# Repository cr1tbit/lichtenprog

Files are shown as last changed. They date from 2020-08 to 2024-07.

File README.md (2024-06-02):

## Lichtenprog - an rather-cheap-USB-to-UART-bridge-with-3v3-out

### Raison d'etre

The device is based on CP2102n - meaning it should work properly on any OS without messy drivers from unknown sources. It's also cheaper than legit FT232 chips.

Why can't I power my stuff from basic USB-to-UART bridges? Some of those serial adapters out there have basic 3.3V-out bulitin, coming usually from main IC's LDO output. Being able to supply like 100 miliamps. I want my full 500mA from the USB! Seriously, throwing that external LDO costs like 10 cents.

I also added an simple circut for estimating the connected device's current draw. You may left it unpopulated, to save like another 70c.

Honestly, I've found myself using this board to supply my 3v3 devices from wallplugs, it's just convenient to have like 10 of those.

## Customizing your Lichtenprog

After soldering your device, you may want to reprogram the CP2102n a little bit, in order to set:
 * TX/RX leds functionality (by default disabled)
 * Max current draw USB descriptor
 * Your custom name and manufacturer name (yay!)

Please, just do not modify PID and VID, or els you risk effectively bricking your brand new 3$ device.

To modify these values, you may use official "xpressconfigurator" from SiLabs

I couldn't make this tool to work on linux though - take a look at this CLI-based project, which should allow setting up basic stuff.

https://github.com/cr1tbit/cp210x-cfg

## Photo (outdated)

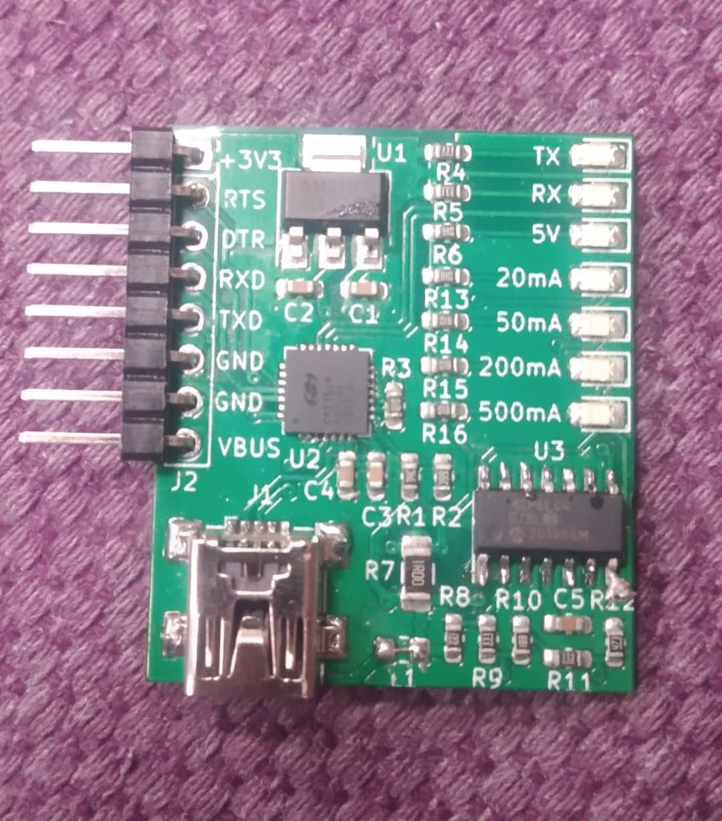
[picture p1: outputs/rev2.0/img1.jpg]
lichtenprog rev 2.0 photo


## License
The hardware design files, including schematics and PCB layout, are licensed under the CERN Open Hardware Licence v2 CERN-OHL-P.

All documentation is released under CC BY-SA 4.0

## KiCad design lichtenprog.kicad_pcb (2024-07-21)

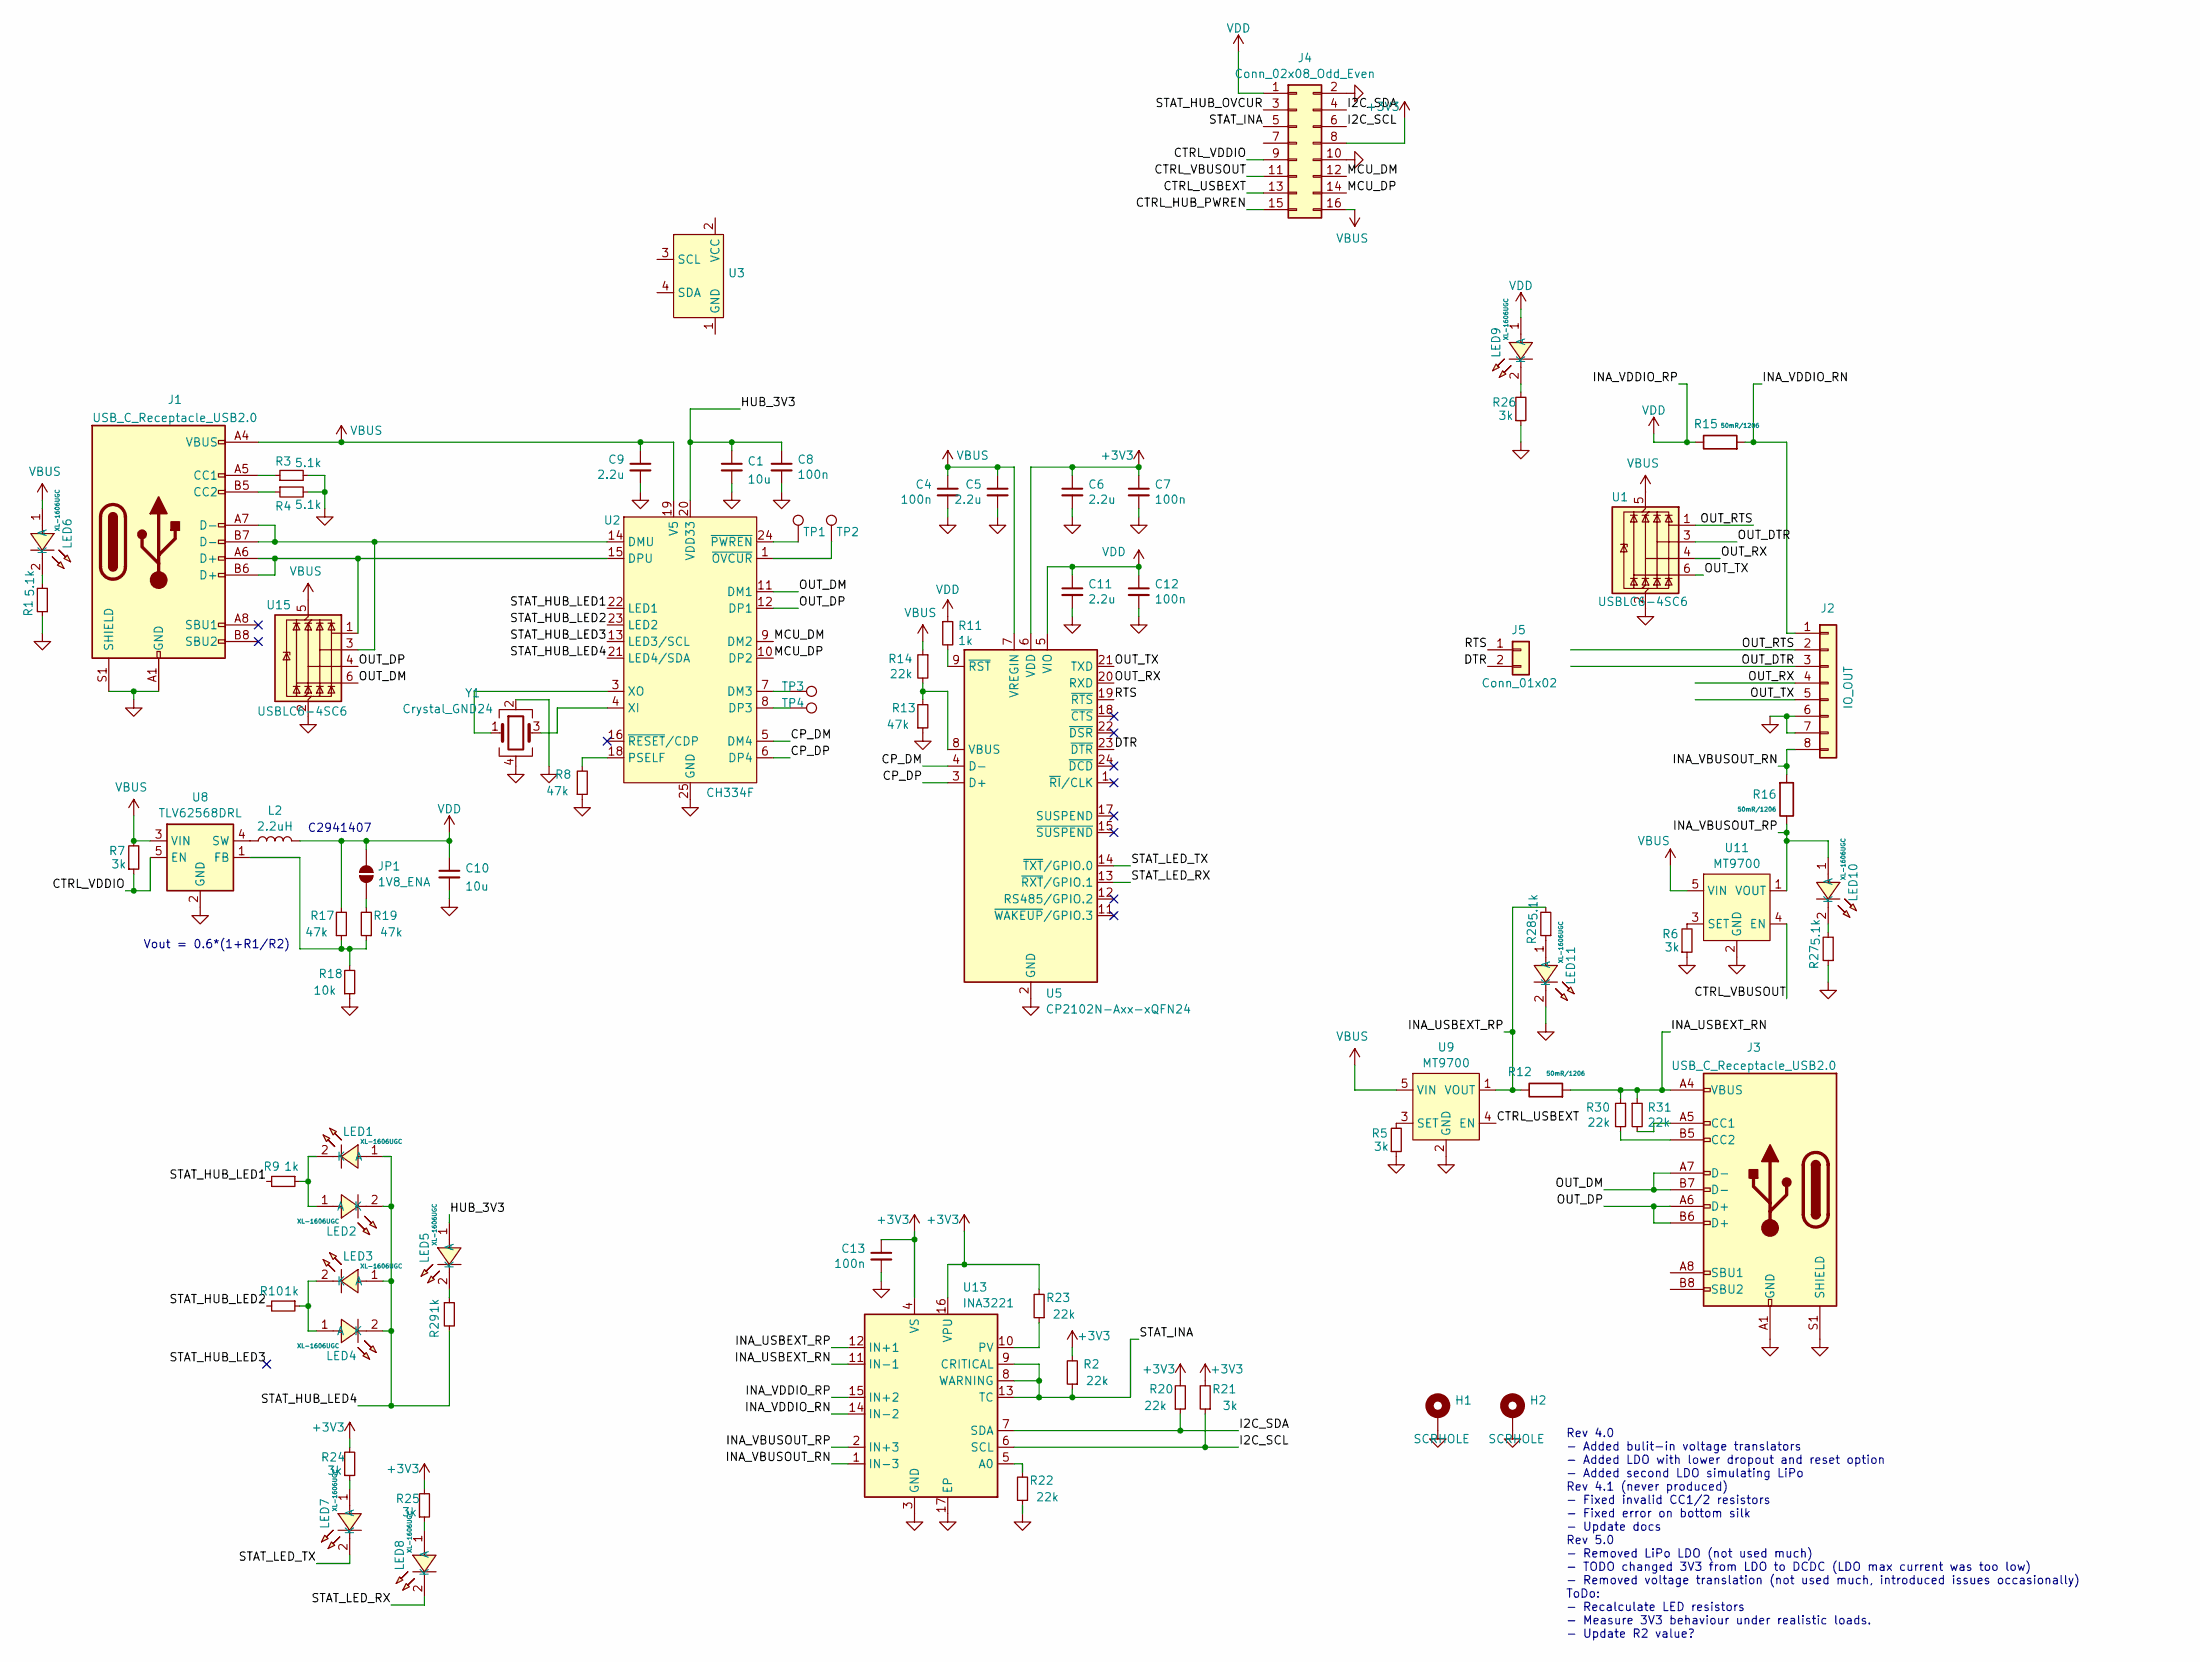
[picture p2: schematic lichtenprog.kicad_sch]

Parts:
C1, C10: 10u; C_0603_1608Metric; LCSC C19702
C4, C7, C8, C12, C13: 100n; C_0402_1005Metric; LCSC C1525
C5, C6, C9, C11: 2.2u; C_0603_1608Metric; LCSC C12530
H1, H2: SCRHOLE; MountingHole_2.2mm_M2_ISO7380_Pad
J1, J3: USB_C_Receptacle_USB2.0; USB_C_Receptacle_HRO_TYPE-C-31-M-12; LCSC C165948
J2: IO_OUT; PinHeader_1x08_P2.54mm_Vertical; LCSC C0000
J4: Conn_02x08_Odd_Even; PinSocket_2x08_P1.27mm_Vertical_SMD
J5: Conn_01x02; PinHeader_1x02_P2.54mm_Vertical
JP1: 1V8_ENA; SolderJumper-2_P1.3mm_Open_RoundedPad1.0x1.5mm
L2: 2.2uH; L_Sunlord_MWSA0412S
LED1, LED2, LED3, LED4, LED5, LED6, LED7, LED8, LED9, LED10, LED11: XL-1606UGC; LED-SMD_L1.7-W1.1-R-RD_GREEN; LCSC Part C965863
R1, R3, R4, R27, R28: 5.1k; R_0402_1005Metric; LCSC C25117
R2, R14, R20, R22, R23, R30, R31: 22k; R_0402_1005Metric; LCSC C25768
R5, R6, R7, R21, R24, R25, R26: 3k; R_0402_1005Metric; LCSC C25768
R8, R13: 47k; R_0402_1005Metric; LCSC C25792
R9, R10, R29: 1k; R_0402_1005Metric; LCSC C25768
R11: 1k; R_0402_1005Metric; LCSC C11702
R12, R15, R16: 50mR/1206; R_1206_3216Metric_Pad1.30x1.75mm_HandSolder; LCSC C601102
R17, R19: 47k; R_0402_1005Metric; LCSC C25768
R18: 10k; R_0402_1005Metric; LCSC C25792
TP1, TP2, TP3, TP4: TestPoint; TestPoint_Pad_D1.0mm
U1, U15: USBLC6-4SC6; SOT-23-6
U2: CH334F; QFN-24_L4.0-W4.0-P0.50-BL-EP2.8; LCSC Part C5187527
U3: OLED_4Pin_128x64_new
U5: CP2102N-Axx-xQFN24; QFN-24-1EP_4x4mm_P0.5mm_EP2.6x2.6mm
U8: TLV62568DRL; SOT-563
U9, U11: MT9700; SOT-23-5_L3.0-W1.7-P0.95-LS2.8-BR; LCSC Part C89855
U13: INA3221; Texas_RGV0016A_VQFN-16-1EP_4x4mm_P0.65mm_EP2.1x2.1mm
Y1: Crystal_GND24; Crystal_SMD_3225-4Pin_3.2x2.5mm

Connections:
+3V3: C6.1, C7.1, C13.1, J4.8, R2.2, R20.2, R21.2, R23.2, R24.2, R25.2, U5.6 (VDD), U13.4 (VS), U13.16 (VPU)
/CP_DM: U2.5 (DM4), U5.4 (D-)
/CP_DP: U2.6 (DP4), U5.3 (D+)
/CTRL_HUB_PWREN: J4.15
/CTRL_USBEXT: J4.13, U9.4 (EN)
/CTRL_VBUSOUT: J4.11, U11.4 (EN)
/CTRL_VDDIO: J4.9, R7.1, U8.5 (EN)
/DTR: J5.2, U5.23 (~DTR)
/HUB_3V3: C1.1, C8.1, LED5.1 (A), U2.20 (VDD33)
/I2C_SCL: J4.6, R21.1, U13.6 (SCL)
/I2C_SDA: J4.4, R20.1, U13.7 (SDA)
/INA_USBEXT_RN: J3.A4 (VBUS), J3.A9 (VBUS), J3.B4 (VBUS), J3.B9 (VBUS), R12.2, R30.1, R31.1, U13.11 (IN-1)
/INA_USBEXT_RP: R12.1, R28.2, U9.1 (VOUT), U13.12 (IN+1)
/INA_VBUSOUT_RN: J2.8, R16.2, U13.1 (IN-3)
/INA_VBUSOUT_RP: LED10.1 (A), R16.1, U11.1 (VOUT), U13.2 (IN+3)
/INA_VDDIO_RN: J2.1, R15.2, U13.14 (IN-2)
/MCU_DM: J4.12, U2.9 (DM2)
/MCU_DP: J4.14, U2.10 (DP2)
/OUT_DM: J3.A7 (D-), J3.B7 (D-), U2.11 (DM1), U15.6 (I/O4)
/OUT_DP: J3.A6 (D+), J3.B6 (D+), U2.12 (DP1), U15.4 (I/O3)
/OUT_DTR: J2.3, U1.3 (I/O2)
/OUT_RTS: J2.2, U1.1 (I/O1)
/OUT_RX: J2.4, U1.4 (I/O3), U5.20 (RXD)
/OUT_TX: J2.5, U1.6 (I/O4), U5.21 (TXD)
/RTS: J5.1, U5.19 (~RTS)
/STAT_HUB_LED1: R9.2, U2.22 (LED1)
/STAT_HUB_LED2: R10.2, U2.23 (LED2)
/STAT_HUB_LED3: U2.13 (LED3/SCL)
/STAT_HUB_LED4: LED1.1 (A), LED2.2 (K), LED3.1 (A), LED4.2 (K), R29.2, U2.21 (LED4/SDA)
/STAT_HUB_OVCUR: J4.3
/STAT_INA: J4.5, R2.1, U13.8 (WARNING), U13.9 (CRITICAL), U13.13 (TC)
/STAT_LED_RX: LED8.2 (K), U5.13 (~RXT/GPIO.1)
/STAT_LED_TX: LED7.2 (K), U5.14 (~TXT/GPIO.0)
GND: C1.2, C4.2, C5.2, C6.2, C7.2, C8.2, C9.2, C10.2, C11.2, C12.2, C13.2, H1.1, H2.1, J1.A1 (GND), J1.A12 (GND), J1.B1 (GND), J1.B12 (GND), J1.S1 (SHIELD), J2.6, J2.7, J3.A1 (GND), J3.A12 (GND), J3.B1 (GND), J3.B12 (GND), J3.S1 (SHIELD), J4.2, J4.10, LED11.2 (K), R1.1, R3.2, R4.2, R5.1, R6.1, R8.1, R13.1, R18.1, R22.1, R26.1, R27.1, U1.2 (GND), U2.25 (GND), U5.2 (GND), U5.25 (GND), U8.2 (GND), U9.2 (GND), U11.2 (GND), U13.3 (GND), U13.17 (EP), U15.2 (GND), Y1.2, Y1.4
unnamed: J1.A5 (CC1), R3.1
unnamed: J1.B5 (CC2), R4.1
unnamed: J3.A5 (CC1), R31.2
unnamed: J3.B5 (CC2), R30.2
unnamed: JP1.1 (A), R19.2
unnamed: LED1.2 (K), LED2.1 (A), R9.1
unnamed: LED3.2 (K), LED4.1 (A), R10.1
unnamed: LED5.2 (K), R29.1
unnamed: LED6.2 (K), R1.2
unnamed: LED7.1 (A), R24.1
unnamed: LED8.1 (A), R25.1
unnamed: LED9.2 (K), R26.2
unnamed: LED10.2 (K), R27.2
unnamed: LED11.1 (A), R28.1
unnamed: TP3.1, U2.7 (DM3)
unnamed: TP4.1, U2.8 (DP3)
unnamed: R8.2, U2.18 (PSELF)
unnamed: U2.4 (XI), Y1.3
unnamed: U2.3 (XO), Y1.1
unnamed: TP2.1, U2.1 (~OVCUR)
unnamed: TP1.1, U2.24 (~PWREN)
unnamed: R13.2, R14.2, U5.8 (VBUS)
unnamed: R11.2, U5.9 (~RST)
unnamed: R17.1, R18.2, R19.1, U8.1 (FB)
unnamed: L2.1, U8.4 (SW)
unnamed: R5.2, U9.3 (SET)
unnamed: R6.2, U11.3 (SET)
unnamed: R22.2, U13.5 (A0)
unnamed: R23.1, U13.10 (PV)
unnamed: J1.A6 (D+), J1.B6 (D+), U2.15 (DPU), U15.1 (I/O1)
unnamed: J1.A7 (D-), J1.B7 (D-), U2.14 (DMU), U15.3 (I/O2)
VBUS: C4.1, C5.1, C9.1, J1.A4 (VBUS), J1.A9 (VBUS), J1.B4 (VBUS), J1.B9 (VBUS), J4.16, LED6.1 (A), R7.2, R14.1, U1.5 (VBUS), U2.19 (V5), U5.7 (VREGIN), U8.3 (VIN), U9.5 (VIN), U11.5 (VIN), U15.5 (VBUS)
VDD: C10.1, C11.1, C12.1, J4.1, JP1.2 (B), L2.2, LED9.1 (A), R11.1, R15.1, R17.2, U5.5 (VIO), U13.15 (IN+2)

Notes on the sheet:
C2941407
Vout = 0.6*(1+R1/R2)
Rev 4.0 - Added bulit-in voltage translators - Added LDO with lower dropout and reset option - Added second LDO simulating LiPo Rev 4.1 (never produced) - Fixed invalid CC1/2 resistors - Fixed error on bottom silk - Update docs Rev 5.0 - Removed LiPo LDO (not used much) - TODO changed 3V3 from LDO 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

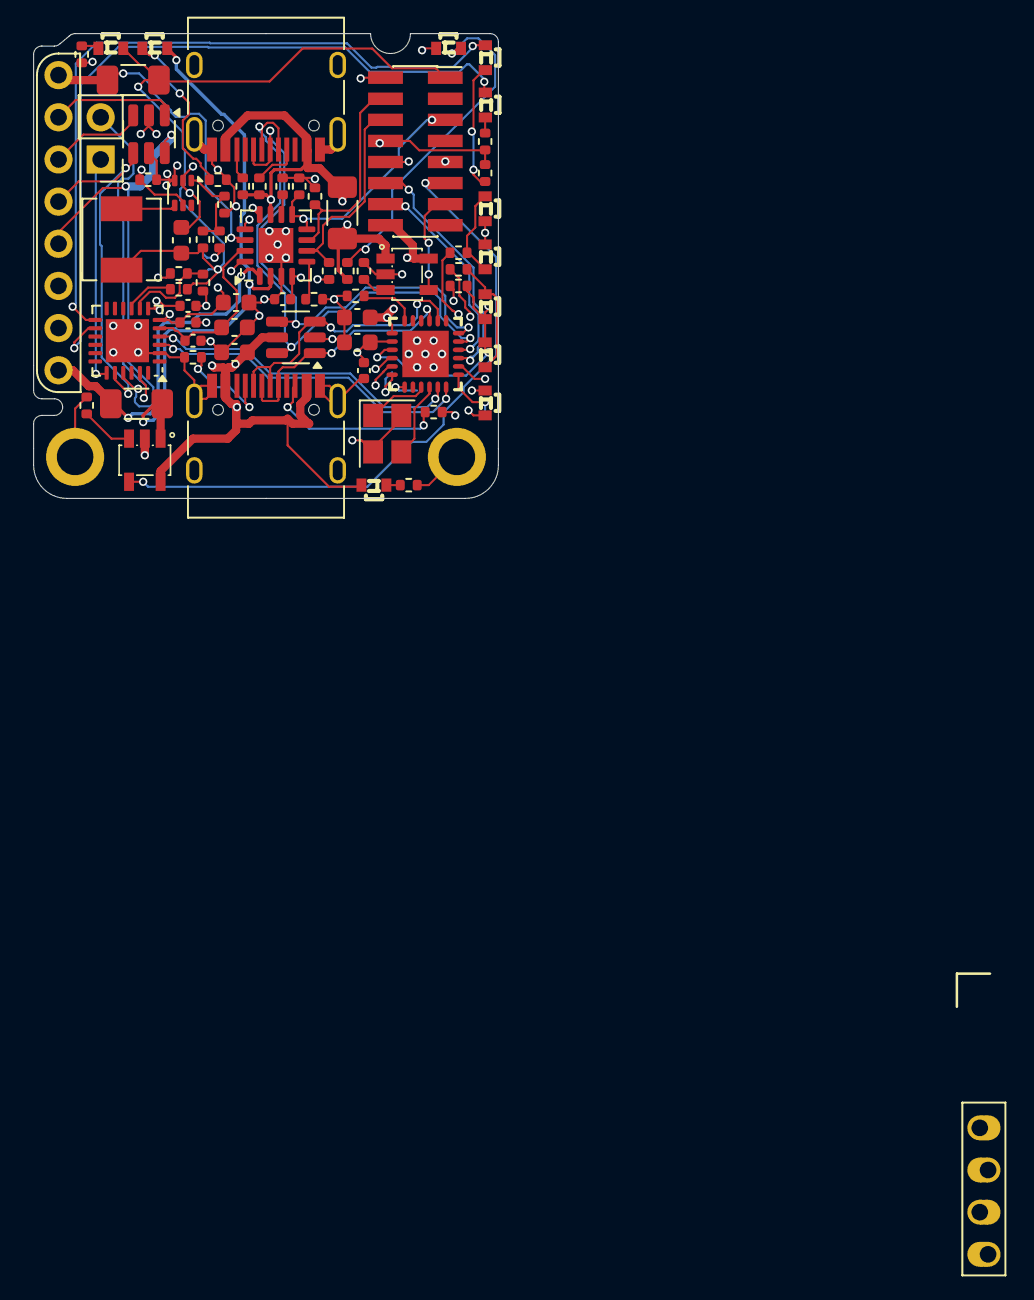
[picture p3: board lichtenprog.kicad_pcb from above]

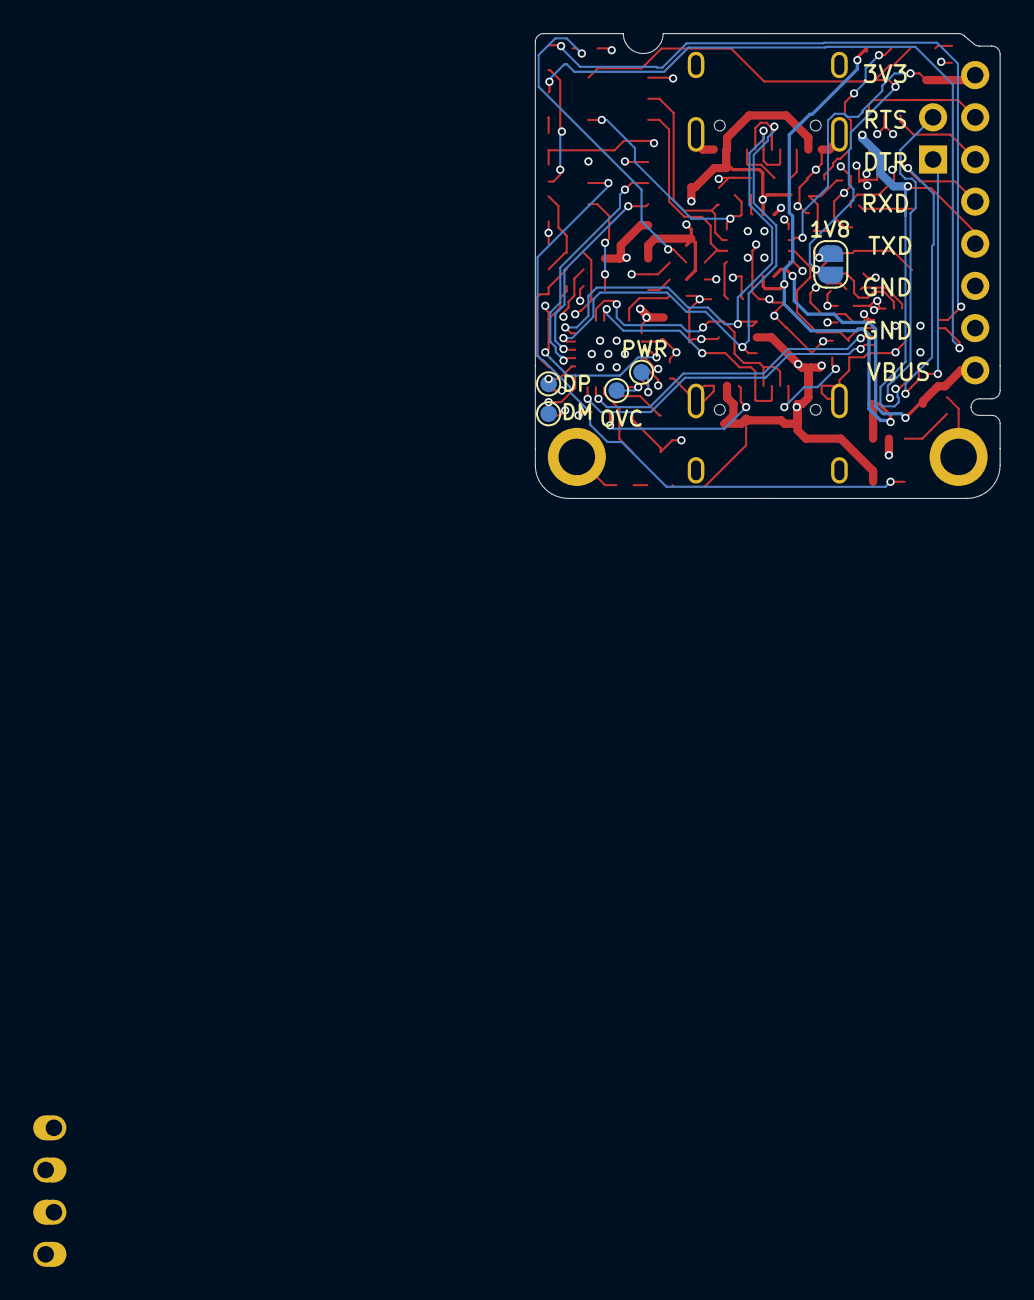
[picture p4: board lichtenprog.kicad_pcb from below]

Board: 4 copper layers, 28.0 x 28.0 mm, 76 parts (5 on the bottom side), 64 nets.

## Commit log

2020-02-06 1st rev
    [bom.csv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]
2020-02-06 adjusting BOM and cpl for production
    [bom.csv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]
2020-05-19 1st rev. 3d model
    [lichtenprog.step]
2020-05-19 rev 2 schematic and PCB do-over
    [lichtenprog.kicad_pcb, lichtenprog.sch]
2020-05-22 finishing PCB, adding description
    [lichtenprog.kicad_pcb]
2020-05-31 fab outputs for rev 2.0
    [bom.csv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]
2022-04-15 changing pc
    [lichtenprog.kicad_pcb, lichtenprog.kicad_sch]
2022-09-15 some PCB swag, preparing JLC BOM
    [lichtenprog.kicad_pcb, lichtenprog.kicad_sch]
2024-06-02 repo cleanup before next rev
    [bom.csv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]
2024-06-02 set proper license, some cleanup
    [lichtenprog.csv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]
2024-07-21 route complt
    [lichtenprog.kicad_pcb, lichtenprog.kicad_sch]
